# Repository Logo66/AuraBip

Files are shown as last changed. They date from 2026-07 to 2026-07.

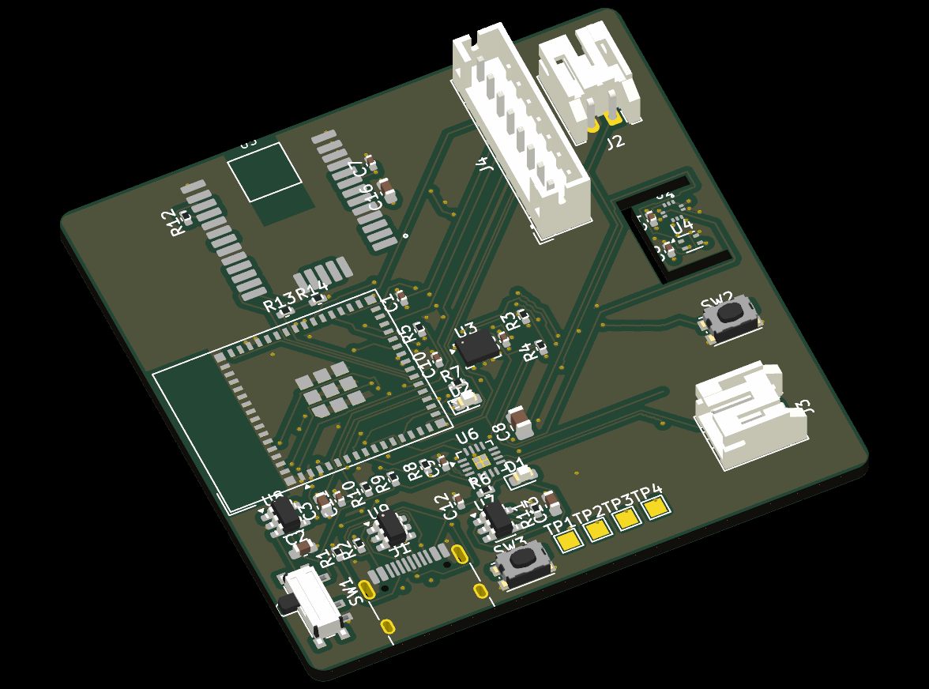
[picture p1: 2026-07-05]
hardware/project/news_persp.jpg

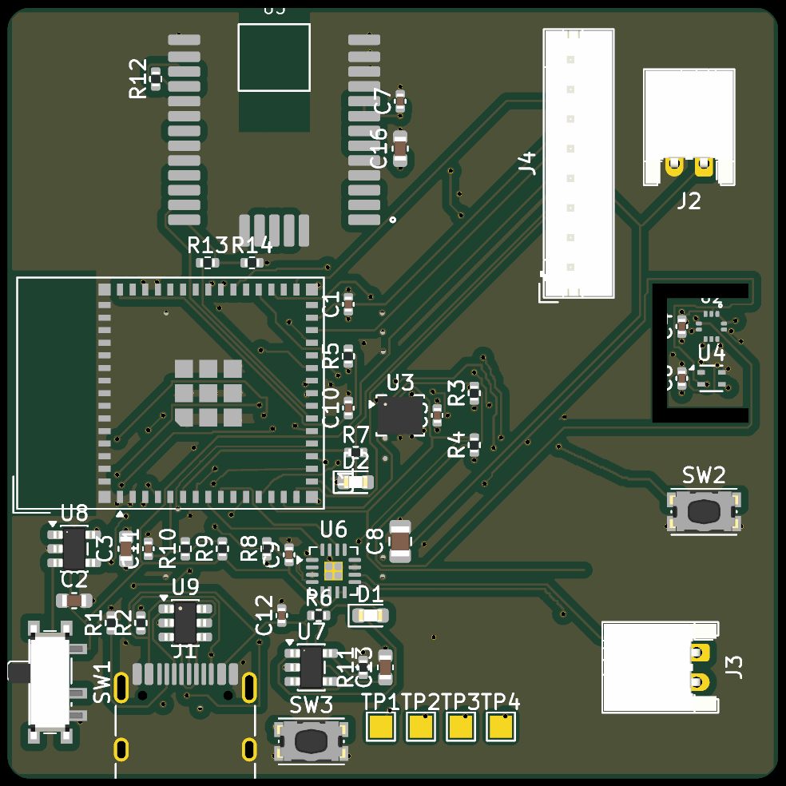
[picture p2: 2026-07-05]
hardware/project/news_top.jpg

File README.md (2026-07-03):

# AuraBip — BLE-Vario auf Heltec V4 (Arbeitstitel)

Minimalistisches BLE-Vario im Stodeus-Stil: Heltec WiFi LoRa 32 V4 + GNSS +
BMP581 + LSM6DSO32 + SHT40. OLED zeigt nur das Nötigste, maximal gross.
Zwei Varianten: **silent** (BLE+Display) und **audio** (I2S-Verstärker,
Vario-Ton + Sprachansagen).

© 2026 KIE Engineering. Proprietär. Clean-Room-Regel wie WindBuddy:
kein Code aus GPL/CC-BY-NC-Projekten (GXAirCom, SoftRF, etc.).
Erlaubt: RadioLib/NimBLE/U8g2 als Bibliotheken (MIT/BSD), öffentliche
Protokoll-Spezifikationen (LK8EX1, NMEA).

## Kernidee "Instant Vario"

Reines Baro-Vario ist träge und böenempfindlich. Die Franzosen (Stodeus)
koppeln deshalb Beschleunigungssensor + Barometer. Wir machen dasselbe:
Kalman-Filter mit BMP581 (Messung, ~50 Hz) + LSM6DSO32 Vertikal-
beschleunigung (Prädiktion, ~200 Hz). Ergebnis: Ansprechzeit <100 ms statt
~1 s, ohne Zappeln.

## BLE-Protokoll (Kompatibilität zu XCTrack / XCSoar / SkyDrop-Apps)

Nordic UART Service (NUS), Notify-Stream mit:
- `$LK8EX1,<press_Pa>,<alt_m>,<vario_cm_s>,<temp_C>,<batt>*CS` — 5 Hz
- NMEA `$GPGGA` / `$GPRMC` Passthrough vom GNSS — 1 Hz
⚠️ VERIFY: LK8EX1-Feldreihenfolge/Checksumme gegen offizielle Doku (T1).

## Display-Philosophie

128×64 OLED, eine einzige Ansicht im Flug:
```
+----------------------+
|  +2.4          ← Vario, riesig (32 px Ziffern)
|  1847 m   34 km/h    ← Alt + GPS-Speed, klein
+----------------------+
```
Kein Menü im Flug. Konfiguration über BLE (BipLink-Prinzip) — Ticket T5.

## Audio-Variante — Realitätscheck

"High Quality Sprach- und Varioton" geht NICHT über den nackten Piezo.
Stodeus-Qualität heisst: richtiger Lautsprecher + Verstärker.
Unser Weg: **MAX98357A I2S-Amp (~3 CHF) + 1 W / 8 Ω Lautsprecher 20–28 mm**.
- Varioton: Synthese direkt auf dem S3 (Sinus/Rechteck, Tonhöhe+Rate aus Vz)
- Sprache: WAV-Samples (16 kHz mono) im 16-MB-Flash — Ansagen Höhe/Speed/
  Steigen auf Doppeltipp (IMU-Tap-Detection des LSM6DSO32, kein Taster nötig!)
Samples: selbst mit TTS generieren (de/en/es — es für Kolumbien 😉).

## Hardware-Verkabelung (v0.1 Prototyp)

| Signal | Heltec V4 Pin | Anmerkung |
|---|---|---|
| I2C SDA/SCL | 17 / 18 (⚠️ VERIFY am V4-Schema) | BMP581 0x47, LSM6DSO32 0x6A, SHT40 0x44 — Ivos Standard-Map |
| GNSS | SH1.25-8P Connector | ⚠️ VERIFY Pinout/UART lt. V4-Doku (T2) |
| OLED | onboard | SSD1306 128×64 |
| I2S (audio) | BCLK/LRCK/DIN frei wählen | in config.h |

## Strategie-Notiz

Hardware-Kosten ~35–45 CHF (Board+Sensoren+GNSS). Als Bausatz das perfekte
Einstiegsprodukt unterhalb der Aura Krücke — und der SX1262 ist ja onboard:
FANET-Upgrade per Firmware-Update ist der eingebaute Upsell (v2).

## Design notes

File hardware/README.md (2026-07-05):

# AuraBip audio — Hardware v0.1 (Serienprodukt)

© 2026 KIE Engineering. Proprietär.

Kompaktes BLE-Vario mit Ton-/Sprachausgabe **und FANET-TX** (FANET→OGN;
ADS-L-ready für den kommenden Conspicuity-Standard): **36×52 mm, 4 Lagen, doppelseitig bestückt**.
Vorderseite: MCU, Sensorik, GNSS, Audio, Power. Rückseite: E22-900M22S
(SX1262) + u.FL-Antennenbuchse. OLED-Modul gesteckt über der Vorderseite,
Akku (LiPo 802030) und Lautsprecher extern per JST-PH.

## Struktur

```
hardware/
  BOM.md          Stückliste + bewusste Design-Entscheide + VERIFY-Tickets
  PINMAP.md       GPIO-Zuordnung, Power-Topologie, komplette Netzliste
  lib/            aurabip.kicad_sym + aurabip.pretty (eigene Symbole/Footprints)
  project/        aurabip.kicad_sch / aurabip.kicad_pcb (generiert!)
  scripts/        generate_schematic.py / generate_pcb.py / symlib.py
  route/          FreeRouting-Pipeline (fanout -> DSN -> route -> import -> DRC)
```

**Alles generiert:** Schema und PCB entstehen aus den Python-Skripten —
Änderungen bitte dort machen und neu generieren, nicht im GUI editieren
(sonst divergiert die Quelle der Wahrheit). Workflow:

```powershell
# 1. Schema (schreibt auch lib/aurabip.kicad_sym + Lib-Tables)
& "C:\Program Files\KiCad\10.0\bin\python.exe" scripts\generate_schematic.py
# 2. ERC
& "C:\Program Files\KiCad\10.0\bin\kicad-cli.exe" sch erc project\aurabip.kicad_sch
# 3. PCB (Platzierung + Zonen, ohne Tracks; zieht Netzliste aus dem Schema)
& "C:\Program Files\KiCad\10.0\bin\python.exe" scripts\generate_pcb.py
# 4. Routing + DRC
powershell -File route\run_autoroute.ps1   # -> project\aurabip_routed.kicad_pcb
```

## Floorplan (Blick von oben)

```
+--------------------------------+
|      L96 GNSS (Patch oben)     |  <- Antenne Richtung Himmel
|                        [AKKU]  |
| ESP32-S3    BMP581  SHT40      |
| (Antenne    LSM6DSO32   [OLED- |
|  -> links)  Pullups      Hdr]  |
| LDO  Teiler  MAX98357A         |
| SW1  USBLC6  Lader  [SPEAKER]  |
| [RST] USB-C [BOOT]  Testpads   |
+--------------------------------+
```

- **ESP32-Antenne**: linke Kante, Kupfer-Keepout auf allen Lagen (x 0–6.0, y 17.7–34.3)
- **L96-Patch**: obere Kante, GND-Lage bleibt darunter (Quectel-Empfehlung, VERIFY T-H5)
- **BMP581/SHT40**: nahe Boardkante; fürs Gehäuse Druckausgleichs-/Lüftungsöffnung vorsehen
- **Rückseite**: E22-900M22S mittig (Handbestückung), u.FL darunter — 868-Flexantenne
  im Gehäuse verlegen, weg von GNSS-Patch und BLE-Antenne (T-H8)
- Lagen: F=Signal+GND-Pour, In1=GND, In2=+3V3, B=Signal+GND-Pour

## Fertigung

- JLCPCB 4-Lagen, 1.6 mm, min. Track/Clearance 0.10 mm (Via 0.5/0.3),
  Bohrloch→Kupfer 0.2 mm — Standardprozess (T-H1 verifizieren)
- SMT-Bestückung (Vorderseite): alle Passiven 0402/0603 aus JLC-Basic-Sortiment
- Handbestückung: L96, JST-Stecker, OLED-Header, Rückseite (E22, u.FL, C14/C15)

## Firmware-Anpassung

Serien-Board ≠ Heltec-Prototyp — `src/config.h` braucht die Pin-Werte aus
[PINMAP.md](PINMAP.md) (I2C 8/9, GNSS 17/18, I2S 4/5/6, neu: AMP_SD 7,
VBAT_ADC 1, LED 2, BTN 0, LoRa-SPI 21/12/11/13 + BUSY 14/DIO1 3/RST 15/
TXEN 16/RXEN 37; OLED auf dem Sensorbus, kein Vext).

**FANET-TX**: Encoder aus WindBuddy `lib/fanet` übernehmen (eigener
Clean-Room-Code, Tracking Typ 1 statt Wetter Typ 4). RadioLib mit
`setRfSwitchPins(RXEN, TXEN)`. TX-Leistung hart ≤ 14 dBm ERP (T-H8),
nur im Flug senden, Adresse/Manufacturer wie WindBuddy-Konvention.

## Offene VERIFY-Tickets (vor Bestellung!)

| Ticket | Was |
|---|---|
| T-H1 | LCSC-Nummern + Lagerbestand aller Positionen |
| T-H2 | **L96-Padout** gegen Quectel Hardware Design Guide (Footprint ist Annahme!) |
| T-H3 | MAX98357A: TQFN-Pinnummern + Exposed-Pad-Maß gegen Maxim-Datenblatt |
| T-H4 | LSM6DSO32-Pinout (INT1=Pin 4?) gegen ST-Datenblatt |
| T-H5 | Antennen-Regeln: ESP32-Keepout-Maße + GND unter L96-Patch |
| T-H6 | USB-C-Footprint-Orientierung: Stecker muss über die Boardkante ragen |

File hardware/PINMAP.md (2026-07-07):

# AuraBip audio — Pin-Map & Netzliste v0.1

© 2026 KIE Engineering. Proprietär.

## ESP32-S3-MINI-1 GPIO-Zuordnung

| GPIO | Netz | Funktion | Anmerkung |
|---|---|---|---|
| 0 | BTN_BOOT | Taster BOOT/USER | Strapping; im Betrieb Nutzertaste |
| 1 | VBAT_SENSE | ADC1_CH0, Teiler 1M/1M + 100n | VBAT/2, max 2.15 V ✓ |
| 2 | LED_STATUS | Status-LED (blau) | aktiv high |
| 4 | I2S_BCLK | MAX98357A BCLK | |
| 5 | I2S_LRCK | MAX98357A LRC | |
| 47 | I2S_DOUT | MAX98357A DIN | Routing-Umzug 2026-07-06: von IO6 auf IO47 verlegt |
| 7 | AMP_SD | MAX98357A SD_MODE | high = an (mono L+R/2); 100k-Pullup an 3V3 |
| 8 | I2C_SDA | Sensorbus + OLED | 4.7k-Pullup |
| 9 | I2C_SCL | Sensorbus + OLED | 4.7k-Pullup |
| 10 | IMU_INT1 | LSM6DSO32 INT1 | Tap-Detection / Data-Ready |
| 17 | GNSS_RX | ← L96 TXD | UART1 RX |
| 18 | GNSS_TX | → L96 RXD | UART1 TX |
| 19 | USB_DN | USB D− | über USBLC6 |
| 20 | USB_DP | USB D+ | über USBLC6 |
| 3 | LORA_DIO1 | E22 DIO1 (IRQ) | |
| 11 | SPI2_MOSI | E22 MOSI + OLED DIN | geteilter SPI2-Bus |
| 12 | SPI2_SCK | E22 SCK + OLED CLK | geteilter SPI2-Bus |
| 13 | SPI2_MISO | E22 MISO | OLED hat kein MISO |
| 14 | LORA_BUSY | E22 BUSY | |
| 15 | LORA_RST | E22 NRST | |
| 16 | LORA_TXEN | E22 TXEN | RadioLib setRfSwitchPins |
| 21 | LORA_NSS | E22 NSS | SPI CS LoRa |
| 33 | OLED_CS | Display Chip-Select | |
| 34 | OLED_DC | Display Data/Command | |
| 35 | OLED_RST | Display Reset | |
| 37 | LORA_RXEN | E22 RXEN | RadioLib setRfSwitchPins (IO26 ist Flash-reserviert) |
| EN | ESP_EN | RESET-Taster + 10k-Pullup + 1µF | |

Display: 1.5" 128×128 SSD1327 über SPI (U8g2: `U8G2_SSD1327_WS_128X128` o. ä.,
Controller nach Lieferung verifizieren, T-H9). I2C-Bus bleibt nur für Sensorik.

Frei/Reserve: 6, 38–46, 48 → 4 Testpads (TP1–TP4: 38, 40, 41, 42).
(IO6 seit Routing-Umzug 2026-07-06 frei, I2S_DOUT liegt auf IO47.)

**config.h-Änderungen für Serien-Board** (gegenüber Heltec-Prototyp):
`PIN_I2C_SDA 8, PIN_I2C_SCL 9, PIN_GNSS_RX 17, PIN_GNSS_TX 18,
PIN_I2S_BCLK 4, PIN_I2S_LRCK 5, PIN_I2S_DOUT 47` + neu `PIN_AMP_SD 7,
PIN_VBAT_ADC 1, PIN_LED 2, PIN_BTN 0`. OLED auf demselben Bus (0x3C),
kein Vext, kein separater OLED-Bus.

## Stromversorgung

```
USB-C 5V ──┬── MCP73831 ──── VBAT ──┬── JST-PH Akku (802030, 500 mAh)
           │   (500 mA, STAT→LED)   ├── MAX98357A VDD (22µF Puffer)
           └── USBLC6 ── D+/D−      └── SW1 ─→ AP2112K EN
                                            AP2112K: VBAT → 3V3
3V3 ── ESP32-S3, L96 (VCC+V_BCKP), BMP581, LSM6DSO32, SHT40, OLED,
       Pullups (I2C, AMP_SD, EN)
```

- SW1 schaltet nur das LDO-EN gegen VBAT/GND → Laden funktioniert im Aus-Zustand, kein Laststrom über den Schalter.
- Amp ist bei 3V3=aus über SD_MODE (Pullup an 3V3 → low) im Shutdown (<1 µA).
- L96 V_BCKP an 3V3: kein Warmstart nach „Aus" (bewusst — Backup-Zelle gespart; Kaltstart ~35 s).

## I2C-Bus (400 kHz, ein Bus)

| Gerät | Adresse |
|---|---|
| BMP581 | 0x47 (SDO→3V3) |
| LSM6DSO32 | 0x6A (SA0→GND) |
| SHT40 | 0x44 |
| OLED SSD1306 | 0x3C |

## Vollständige Netzliste (Referenz für Generatoren)

| Netz | Pins |
|---|---|
| GND | alle GND-Pads, USB-Shield, EP U6, CC-Rs low-side n/a |
| VBUS | J1.VBUS, U9.VBUS, U7.IN(4), 100n |
| VBAT | U7.OUT(3), J2.1, U6.VDD, SW1-Mitte n/a → U8.IN(1)+EN-Kette, R-Teiler oben |
| +3V3 | U8.OUT(5), U1.3V3, U2, U3, U4, U5.VCC+V_BCKP, J4.VCC, Pullups |
| USB_DP/USB_DN | J1.D±(A6/B6, A7/B7) ↔ U9 ↔ U1.IO20/IO19 |
| CC1/CC2 | J1.CC1/CC2 → je 5.1k → GND |
| CHG_STAT | U7.STAT(1) → LED grün → 3V3 (aktiv low) |
| PROG | U7.PROG(5) → 2k → GND |
| LDO_EN | U8.EN(3) ← SW1 (VBAT / GND) |
| ESP_EN | U1.EN ← 10k→3V3, 1µF→GND, SW2→GND |
| BTN_BOOT | U1.IO0 ← SW3→GND (interner Pullup) |
| I2C_SDA/SCL | s. oben, 4.7k→3V3 |
| I2S_BCLK/LRCK/DOUT | U1.IO4/5/47 → U6.BCLK/LRC/DIN (DOUT: Routing-Umzug 2026-07-06, IO6→IO47) |
| AMP_SD | U1.IO7 → U6.SD_MODE, 100k→3V3 |
| AMP_OUTP/OUTN | U6.OUT+/OUT− → J3 (Lautsprecher) |
| IMU_INT1 | U3.INT1 → U1.IO10 |
| GNSS_TX_NET | U5.TXD → U1.IO17 |
| GNSS_RX_NET | U5.RXD ← U1.IO18 |
| VBAT_SENSE | Teiler-Mitte → U1.IO1 |
| LED_STATUS | U1.IO2 → 1k → LED blau → GND |
| LORA_NSS/SCK/MOSI/MISO | U1.IO21/12/11/13 → U10 (E22-900M22S) |
| LORA_BUSY/DIO1/RST | U10 → U1.IO14/IO3/IO15 |
| LORA_TXEN/RXEN | U1.IO16/IO37 → U10 |
| LORA_ANT | U10.ANT → J5 (u.FL); E22 an +3V3 (TX 14 dBm ≈ 120 mA ok) |

⚠️ VERIFY: MAX98357A-GAIN-Pin offen lassen = 9 dB (Default). Bei Bedarf
GAIN-Netz auf Lötjumper führen — v0.1: offen.

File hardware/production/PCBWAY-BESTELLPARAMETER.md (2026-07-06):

# PCBWay-Bestellparameter AuraBip v0.1 (für die Offerte)

## PCB (Instant Quote → Standard PCB)
| Parameter | Wert |
|---|---|
| Board size | 52 × 52 mm |
| Quantity | **10** (Prototypen-Charge) |
| Layers | **4** |
| Material | FR-4, TG150 |
| Thickness | 1.6 mm |
| Min track/spacing | **5/5 mil** (0.127 mm Schmalspur-Züge!) |
| Min hole size | 0.3 mm |
| Solder mask | Grün (oder nach Geschmack) |
| Silkscreen | Weiß |
| Surface finish | **ENIG** (0.4-mm-Pitch BMP581 + Stamp-Holes — kein HASL!) |
| Via process | Tenting vias |
| Kupfer | 1 oz außen / 0.5 oz innen (Standard) |
| Besonderheit | **Interne Fräskontur** (Sensor-Insel, C-Schlitz 1 mm) — ist in Edge.Cuts enthalten |

## Assembly (Turnkey, nur Vorderseite)
| Parameter | Wert |
|---|---|
| Seiten | **Nur Top** (Bottom = 4 Teile Handbestückung durch uns: E22, C14, C15) |
| Anzahl | 10 Boards bestücken |
| Teile-Beschaffung | Turnkey (PCBWay beschafft); **U5 (Quectel L96) + U10 (E22) ggf. als Consigned/selbst liefern**, falls Beschaffung teuer |
| Stencil | Ja (framework-los reicht) |
| Dateien | aurabip_gerber.zip · aurabip-bom.csv · aurabip-top-pos.csv (+ bottom-pos nur zur Referenz) |

## Hinweise für die Review durch PCBWay
- 0402-Passive, TQFN-16 (0.5 P), LGA-10 (0.4 P!), LGA-14 (0.5 P), DFN-4
- USB-C-Buchse ragt 1.2 mm über die Kante (Absicht)
- NPTH: Schalter-Justierstifte + USB-Schild
- Bottom-Bauteile im Pick&Place enthalten, aber NICHT bestücken

## Nach Offerten-Eingang prüfen (T-H1)
- [ ] Alle BOM-Zeilen gematcht? (Passive ohne MPN → PCBWay-Vorschlag akzeptieren, X7R/1% reicht)
- [ ] L96 + E22 lieferbar/Preis ok? Sonst consigned liefern
- [ ] ME6217C33M5G verfügbar? (Fallback: AP2112K-3.3, pinkompatibel, dann aber LoRa-TX + BLE-Peak nicht gleichzeitig — FW drosseln)
- [ ] Keine Design-Rückfragen zu Schmalspur/Fräsung offen

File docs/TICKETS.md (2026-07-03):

# AuraBip — Tickets (Claude Code)

Clean-Room-Regel wie WindBuddy gilt. Kein GXAirCom/SoftRF-Code anschauen.

## T1 — LK8EX1 & BLE-Kompatibilität (BLOCKER)
- LK8EX1-Spez beschaffen, Feldkonventionen verifizieren (Batteriefeld!)
- Test gegen XCTrack auf Ivos Handy: verbindet, zeigt Baro-Alt + Vario + GPS?
- BLE-Name/Advertising so, dass XCTrack das Gerät als "BLE Sensor" findet
- DoD: XCTrack fliegt komplett mit AuraBip-Daten (interner Sensor aus)

## T2 — Sensortreiber & GNSS
- BMP581/LSM6DSO32/SHT40-Treiber aus Aura-Monorepo portieren (eigener Code)
- BMP581: OSR/ODR für 50 Hz rauscharm konfigurieren
- V4 GNSS-Connector-Pinout aus Heltec-Doku verifizieren, MAX-M10S anbinden
- RMC-Parser härten (kein strstr-Gefrickel)
- DoD: sensors::init() erkennt alle drei, Live-Werte plausibel

## T3 — Orientierungsschätzung
- verticalAccelApprox() durch Mahony-Filter (Gyro+Accel) ersetzen,
  echte Erd-Frame-Vertikalbeschleunigung
- Kalman-Tuning im Auto-/Treppenhaus-Test, dann Flug
- DoD: Ansprechzeit < 150 ms, kein Zappeln im Geradeausflug

## T4 — Audio-Ausbau (Variante audio)
- WAV-Player aus LittleFS, Mixer (Ansage über gedämpftem Varioton)
- Tap-Detection LSM6DSO32 (Doppeltipp = Ansage Höhe/Speed)
- Sprachsamples de/en/es generieren (TTS), 16 kHz mono
- Lautstärke-Profil: Start laut, konfigurierbar via BLE
- DoD: Doppeltipp -> saubere Sprachansage ohne Knacken, Ton läuft weiter

## T5 — BLE-Konfigurationskanal
- Zweite NUS-Charakteristik (RX): einfache Key=Value-Kommandos
  (QNH, Lautstärke, Klimm-/Sinkschwellen, Sprachwahl)
- Persistenz in NVS
- DoD: Einstellung überlebt Reboot

## T6 — Strom & Gehäuse
- Light-Sleep-Strategie am Boden (kein Steigen 10 min -> Display dim, IMU-Wakeup)
- Verbrauchsmessung beide Varianten; Ziel: >20 h mit 3000er Zelle
- Ivo: Gehäuse-Design (Druck), Lautsprecheröffnung akustisch (Bassreflex-Schlitz)

## Später / v2
- FANET über den onboard SX1262 (lib/fanet aus WindBuddy wiederverwenden!)
- IGC-Logging in Flash

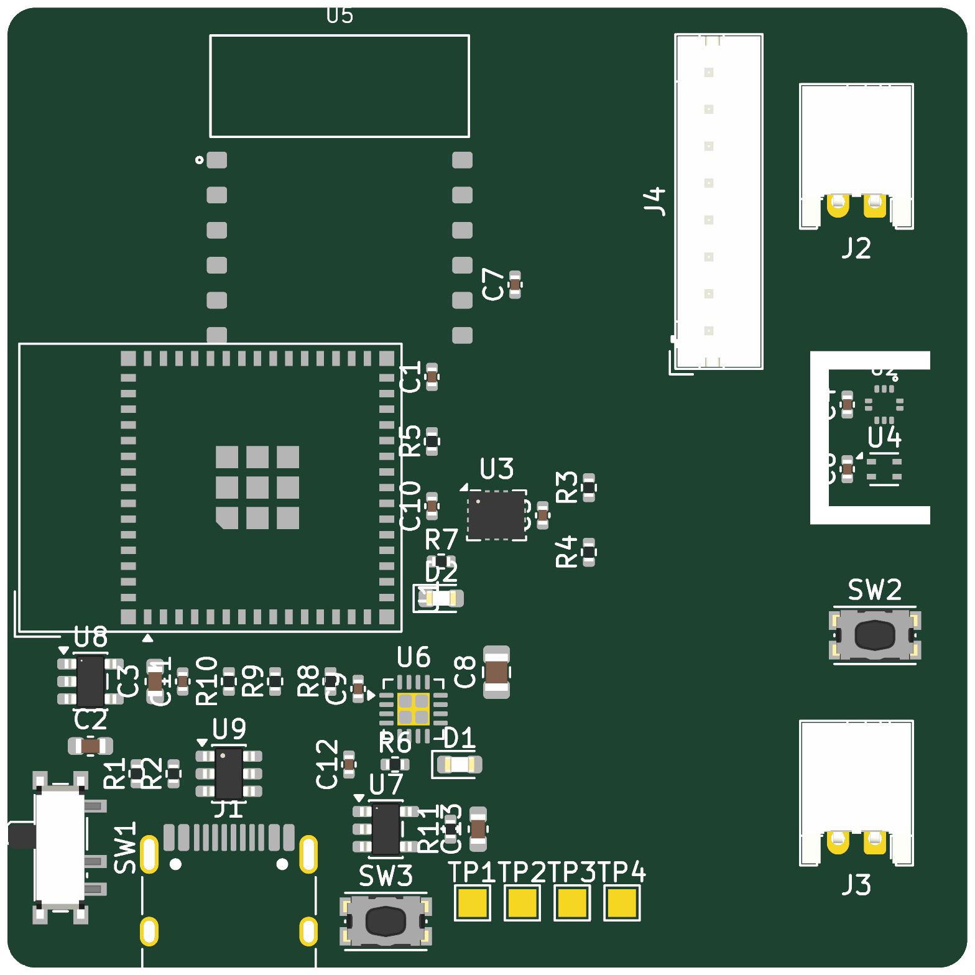
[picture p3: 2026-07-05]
hardware/project/render_52_top.png

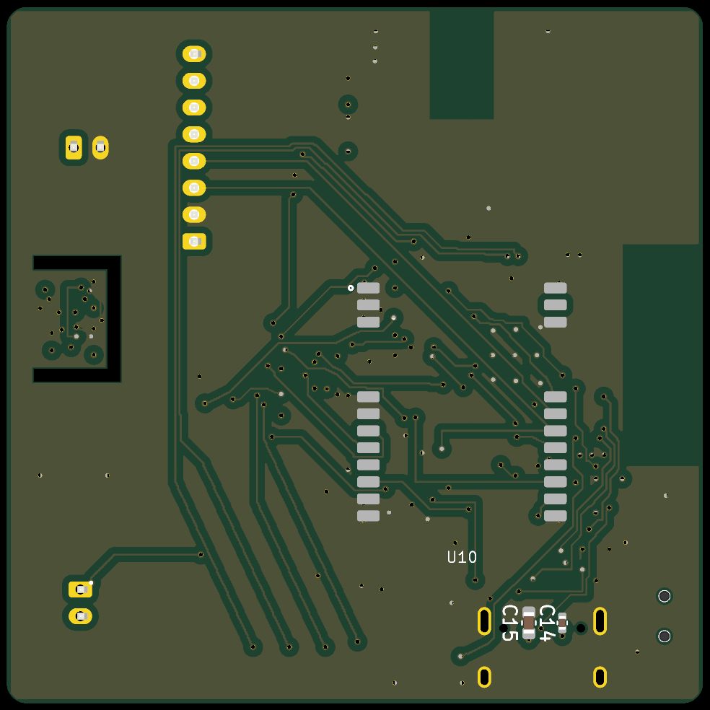
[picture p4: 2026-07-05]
hardware/project/news_bottom.jpg

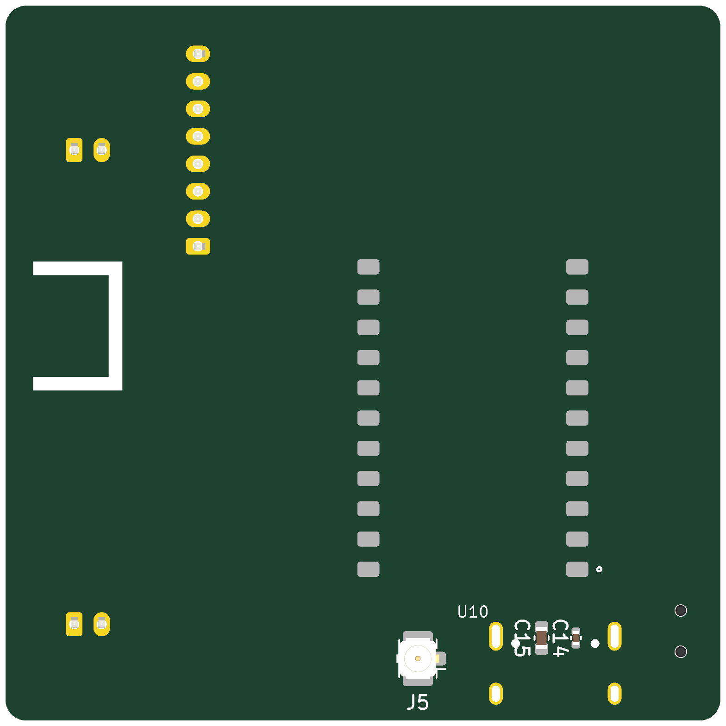
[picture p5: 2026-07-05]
hardware/project/render_52_bottom.png

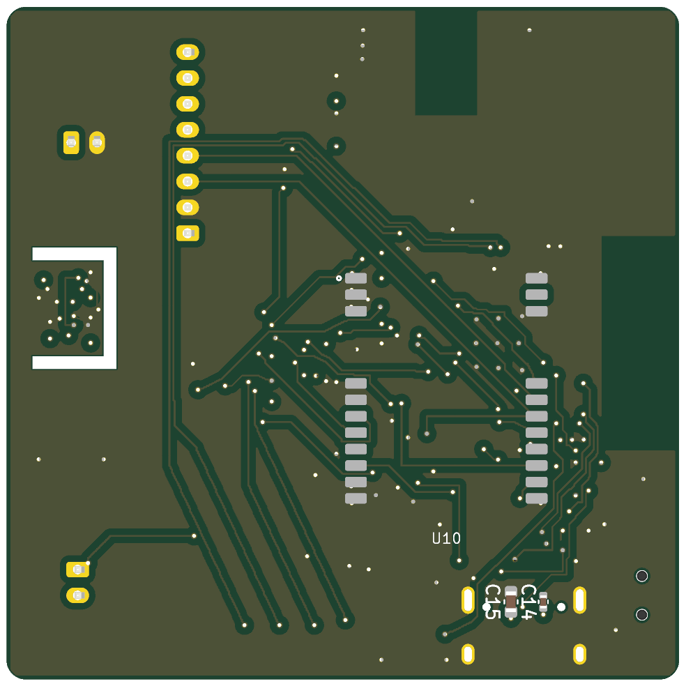
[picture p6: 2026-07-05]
hardware/project/news_bottom.png

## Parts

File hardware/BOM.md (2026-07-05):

# AuraBip audio — BOM v0.1 (Serienprodukt)

© 2026 KIE Engineering. Proprietär.

Ziel: kompaktes BLE-Vario mit Sprach-/Tonausgabe, ~35×48 mm, 4-Lagen-PCB,
JLCPCB-Fertigung (SMT-Bestückung ab Rolle wo möglich).
Alle LCSC-Nummern sind ⚠️ **vor Bestellung zu verifizieren** (Verfügbarkeit dreht schnell).

## Kern

| Ref | Bauteil | Package | Funktion | LCSC (⚠️ prüfen) | ~Preis (1 Stk) |
|---|---|---|---|---|---|
| U1 | **ESP32-S3-MINI-1-N8** | Modul 15.4×15.4 | MCU, BLE 5, natives USB (kein UART-Bridge-Chip nötig), FCC/CE-zertifiziert | C2913204 | 3.20 CHF |
| U2 | **BMP581** | LGA-10 2×2 | Barometer 50 Hz (Kalman-Update), Adr 0x47 | TBD | 2.50 CHF |
| U3 | **LSM6DSO32XTR** | LGA-14 2.5×3 | IMU ±32 g, 200 Hz Prädiktion + Tap-Detection, Adr 0x6A | TBD | 2.80 CHF |
| U4 | **SHT40-AD1B** | DFN-4 1.5×1.5 | Temp/Feuchte, Adr 0x44 | TBD | 1.80 CHF |
| U5 | **Quectel L96-M33** | LCC 14×15 | GNSS MT3333, **integrierte Patch-Antenne** (kein RF-Design-Risiko), 1 Hz NMEA | TBD | 6.50 CHF |
| U6 | **MAX98357AETE+T** | TQFN-16-EP 3×3 | I2S-DAC+3.2W-Class-D-Amp, läuft direkt an VBAT | TBD | 2.20 CHF |

## Power

| Ref | Bauteil | Package | Funktion | LCSC (⚠️ prüfen) | ~Preis |
|---|---|---|---|---|---|
| U10 | **Ebyte E22-900M22S** | Modul 16×26 | SX1262 + TCXO + PA, FANET-TX (Typ 1) → OGN-Sichtbarkeit; GFSK-fähig = **ADS-L-ready** für den kommenden Conspicuity-Standard. TX-Leistung in FW hart auf 14 dBm ERP begrenzt | TBD | 5.50 CHF |
| ANT | **Molex 105262-0001** Flex-Klebeantenne 868/915, u.FL, 100 mm Kabel (Alt.: Taoglas FXP14; -0002 = 150 mm) | im Gehäuse (Wandnische, vertikal) | steckt **direkt auf die IPX-Buchse des E22-Moduls** — null Board-RF, kein eigener Antennenanschluss (J5 entfallen). Nischenmaß im Fusion-Skript anpassen (ant_l/ant_h) | Beta LAYOUT ~8 € | 8.00 CHF |
| U7 | **MCP73831T-2ACI/OT** | SOT-23-5 | LiPo-Lader 1 Zelle, 500 mA (R_PROG 2 kΩ) | C424093 | 0.60 CHF |
| U8 | **ME6217C33M5G** | SOT-23-5 | LDO 3.3 V / **800 mA** (ESP32-BLE-Peak + LoRa-TX + GNSS gleichzeitig; Amp hängt an VBAT). Pinkompatibel zu AP2112K | C82942 (⚠️) | 0.20 CHF |
| U9 | **USBLC6-2SC6** | SOT-23-6 | USB-ESD-Schutz | C7519 | 0.20 CHF |
| J1 | **TYPE-C-31-M-12** (HRO) | USB-C 16P | Laden + Flashen (USB-CDC/DFU) | C165948 | 0.25 CHF |
| J2 | **JST PH 2P** (S2B-PH-K-S) | THT gewinkelt | Akku-Anschluss | TBD | 0.10 CHF |
| BAT | **LiPo 504050**, 3.7 V, **1500 mAh**, 52×42×5 mm, 25 g, −25…+60 °C, Kabel 45 mm, JST-PH 2.0 | extern, unter dem 52×52-Board (Gehäuse-Schacht) | ~10 h Laufzeit bei ~140 mA Mix; Betriebstemp. bis −25 °C ist flugtauglich. ⚠️ **POLARITÄT am Stecker prüfen** — bei LiPo-Herstellern nicht genormt! | ~9 CHF | 9.00 CHF |
| SW1 | **MSK-12C02** | Schiebeschalter | Ein/Aus (schaltet nur LDO-EN, nicht VBAT — Laden geht auch „aus") | TBD | 0.15 CHF |

## Audio & UI

| Ref | Bauteil | Package | Funktion | LCSC (⚠️ prüfen) | ~Preis |
|---|---|---|---|---|---|
| LS1/J3 | **Visaton K 28 WP** (28 mm, 8 Ω, 1 W, spritzwassergeschützte Kunststoffmembran) an JST-PH-Pigtail | — | Varioton + Sprache; WP-Variante wegen Outdoor-Einsatz | Voelkner/RS/Reichelt ~4 CHF | 4.00 CHF |
| J4 | **JST-PH 8-Pin vertikal** (B8B-PH-K-S) + **Waveshare 1.32" OLED** 128×96, 16 Graustufen, SSD1327, SPI | Kabel (liegt Modul bei) | Kein Header — Modul hat **PH2.0-Buchse**, Kabel im Lieferumfang → Display frei im Gehäusedeckel platzierbar. Teilt SPI2 mit E22 (eigener CS); −20…70 °C. T-H9: Kabel-Pinreihenfolge bei Lieferung prüfen | Waveshare/Amazon ~12 CHF | 12.00 CHF |
| SW2 | Taster **RESET** (EN) | SMD 3.9×2.9 | Neustart | TBD | 0.05 CHF |
| SW3 | Taster **BOOT/USER** (GPIO0) | SMD 3.9×2.9 | Strapping + Nutzertaste im Betrieb (Doppeltipp macht die IMU) | TBD | 0.05 CHF |
| D1 | LED grün + R 1 kΩ | 0603 | Lade-Status (MCP73831 STAT) | — | 0.03 CHF |
| D2 | LED blau + R 1 kΩ | 0603 | Status (GPIO2) | — | 0.03 CHF |

## Passiv (0402, JLC Basic Parts)

| Menge | Wert | Funktion |
|---|---|---|
| 2× | 5.1 kΩ | USB-C CC1/CC2 |
| 2× | 4.7 kΩ | I2C-Pullups SDA/SCL |
| 1× | 2 kΩ | MCP73831 PROG (500 mA) |
| 2× | 1 MΩ | VBAT-ADC-Teiler (GPIO1) |
| 1× | 100 kΩ | Amp SD_MODE-Pullup auf 3V3 (aus, wenn 3V3 aus) |
| 1× | 10 kΩ | EN-Pullup (RESET) |
| 8× | 100 nF | Abblock je IC |
| 2× | 10 µF | LDO in/out |
| 1× | 22 µF (0805) | Amp-VBAT-Puffer |
| 1× | 100 nF | ADC-Teiler-Filter |

**Summe Elektronik: ~31 CHF/Stk** (Kleinserie 50 Stk, ohne PCB/Bestückung/Akku/Gehäuse).
PCB+SMT bei JLC (50 Stk, 4-Lagen): ~9 CHF/Board. Akku 802030: ~3 CHF. Antenne 868: ~1 CHF. → **~44 CHF Material.**

## Bewusste Entscheidungen

- **FANET-TX drin** (Änderung 2026-07-03): Elektronische Sichtbarkeit (Conspicuity) ist absehbar — Standard-Kandidat ist **ADS-L**, ein festes Pflichtdatum gibt es noch nicht. SX1262-Modul E22-900M22S: sendet heute FANET→OGN, GFSK-fähig für späteres ADS-L-out per Firmware. **Nur TX** (Tracking Typ 1, FANET→OGN), keine Warnlogik — Warnquellen-Philosophie bleibt. FANET-Encoder aus WindBuddy `lib/fanet` (eigener Clean-Room-Code) wiederverwenden. Modul statt nacktem SX1262: TCXO (Frequenzstabilität bei Kälte!) + fertiges RF-Frontend.
- **Kein USB-UART-Chip**: ESP32-S3 natives USB (GPIO19/20) für Flashen + CDC-Logs.
- **Kein Fuel-Gauge** (v1): VBAT-Teiler an ADC reicht für %-Anzeige. v2-Option: MAX17048.
- **Kein Power-Path** (v1): MCP73831 lädt, System zieht parallel an VBAT. Bekannte Schwäche: Terminierung bei Last ungenau. v2-Option: BQ24074.
- **L96 mit integrierter Antenne** statt ATGM336H+Antenne: teurer, aber null RF-Layout-Risiko und kleiner als Patch+Pigtail.
- **Amp an VBAT**: Audio-Peaks (~1 A kurz) gehen nicht durch den 600-mA-LDO. SD_MODE-Pullup an 3V3 schaltet den Amp mit aus.

## VERIFY-Status (Stand 2026-07-05)

| Ticket | Status |
|---|---|
| T-H2 L96-Padout | ✅ **verifiziert** gegen Quectel HW Design V1.4 (LCC-31, 14×9.6! RF-Brücke R12 + RXD-Teiler R13/R14 ergänzt, Antennen-Keepout 4.8×7.3) |
| T-H3 MAX98357A | ✅ **verifiziert** gegen ADI-Datenblatt Rev 7 (TQFN-Pinout war falsch → korrigiert; Footprint auf EP1.23 gewechselt; GAIN offen = 9 dB bestätigt) |
| T-H4 LSM6DSO32 | ✅ **verifiziert** gegen ST-Datenblatt Rev 1 (Pinout korrekt; Footprint auf ST-LayoutBorder3x4y gewechselt) |
| T-H7 E22-900M22S | ✅ **verifiziert** gegen Ebyte Manual v1.3 (war 14×20/1.27er-Pitch statt 16×26/2.2 — komplett neu; JLC C411293) |
| T-H1 LCSC/PCBWay-Nummern + Lager | ⏳ offen — bei Bestellung gegen PCBWay-Sortiment prüfen |
| T-H5 ESP32-Antennen-Keepout-Maße | ⏳ offen (konservativ ausgelegt) |
| T-H6 USB-C-Überstand | ⏳ offen — 1.2 mm Nase, am ersten Board messen |
| T-H8 Regulatorik 14 dBm ERP + Duty Cycle | ⏳ offen (vor Verkauf, mit Antennengewinn rechnen) |
| T-H9 OLED-Kabel-Aderreihenfolge | ⏳ offen — bei Lieferung Sichtprüfung |

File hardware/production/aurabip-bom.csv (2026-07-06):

Designator | Qty | MPN | Manufacturer | Description | Footprint | Side
C1,C11,C12,C4,C5,C6,C7,C9 | 8 |  |  | MLCC Capacitor X7R 16V 100n C_0402_1005Metric | C_0402_1005Metric | Top
C10 | 1 |  |  | MLCC Capacitor X7R 16V 1u C_0402_1005Metric | C_0402_1005Metric | Top
C13 | 1 |  |  | MLCC Capacitor X7R 16V 4.7u C_0603_1608Metric | C_0603_1608Metric | Top
C14 | 1 |  |  | MLCC Capacitor X7R 16V 100n C_0402_1005Metric | C_0402_1005Metric | Bottom
C15 | 1 |  |  | MLCC Capacitor X7R 16V 10u C_0603_1608Metric | C_0603_1608Metric | Bottom
C16,C2,C3 | 3 |  |  | MLCC Capacitor X7R 16V 10u C_0603_1608Metric | C_0603_1608Metric | Top
C8 | 1 |  |  | MLCC Capacitor X7R 16V 22u C_0805_2012Metric | C_0805_2012Metric | Top
D1 | 1 | 19-217/GHC-YR1S2/3T | Everlight | LED green 0603 | LED_0603_1608Metric | Top
D2 | 1 | 19-217/BHC-ZL1M2RY/3T | Everlight | LED blue 0603 | LED_0603_1608Metric | Top
J1 | 1 | TYPE-C-31-M-12 | HRO | USB-C receptacle 16P | USB_C_Receptacle_HRO_TYPE-C-31-M-12 | Top
J2 | 1 | S2B-PH-K-S | JST | Battery connector PH 2.0 2P, THT | JST_PH_S2B-PH-K_1x02_P2.00mm_Horizontal | Top
J3 | 1 | S2B-PH-K-S | JST | Speaker connector PH 2.0 2P, THT | JST_PH_S2B-PH-K_1x02_P2.00mm_Horizontal | Top
J4 | 1 | B8B-PH-K-S | JST | OLED connector PH 2.0 8P vertical, THT | JST_PH_B8B-PH-K_1x08_P2.00mm_Vertical | Top
R1,R2 | 2 |  |  | Chip Resistor 1% 5.1k R_0402_1005Metric | R_0402_1005Metric | Top
R11,R14 | 2 |  |  | Chip Resistor 1% 2k R_0402_1005Metric | R_0402_1005Metric | Top
R12 | 1 |  |  | Chip Resistor 1% 0R R_0402_1005Metric | R_0402_1005Metric | Top
R3,R4 | 2 |  |  | Chip Resistor 1% 4.7k R_0402_1005Metric | R_0402_1005Metric | Top
R5 | 1 |  |  | Chip Resistor 1% 10k R_0402_1005Metric | R_0402_1005Metric | Top
R13,R6,R7 | 3 |  |  | Chip Resistor 1% 1k R_0402_1005Metric | R_0402_1005Metric | Top
R8 | 1 |  |  | Chip Resistor 1% 100k R_0402_1005Metric | R_0402_1005Metric | Top
R10,R9 | 2 |  |  | Chip Resistor 1% 1M R_0402_1005Metric | R_0402_1005Metric | Top
SW1 | 1 | MSK-12C02 | Shouhan | Slide switch | SW_SPDT_PCM12 | Top
SW2 | 1 | KMR221GLFS | C&K | Tactile switch RESET | SW_Push_1P1T_NO_CK_KMR2 | Top
SW3 | 1 | KMR221GLFS | C&K | Tactile switch BOOT | SW_Push_1P1T_NO_CK_KMR2 | Top
TP1,TP2,TP3,TP4 | 4 |  |  | TP TP TestPoint_Pad_1.5x1.5mm | TestPoint_Pad_1.5x1.5mm | Top
U1 | 1 | ESP32-S3-MINI-1-N8 | Espressif | WiFi/BLE module, 8MB flash | ESP32-S2-MINI-1 | Top
U10 | 1 | E22-900M22S | Ebyte | SX1262 LoRa module, stamp holes, bottom side | E22_900M22S | Bottom
U2 | 1 | BMP581 | Bosch | Barometric pressure sensor LGA-10 - open port, do NOT wash | BMP581_LGA-10_2x2mm | Top
U3 | 1 | LSM6DSO32XTR | ST | IMU +/-32g LGA-14 | LGA-14_3x2.5mm_P0.5mm_LayoutBorder3x4y | Top
U4 | 1 | SHT40-AD1B-R2 | Sensirion | Temp/humidity sensor DFN-4 | Sensirion_DFN-4_1.5x1.5mm_P0.8mm_SHT4x_NoCentralPad | Top
U5 | 1 | L96-M33 | Quectel | GNSS module with integrated antenna | Quectel_L96 | Top
U6 | 1 | MAX98357AETE+T | Analog Devices | I2S Class-D amplifier TQFN-16 | TQFN-16-1EP_3x3mm_P0.5mm_EP1.23x1.23mm | Top
U7 | 1 | MCP73831T-2ACI/OT | Microchip | LiPo charger SOT-23-5 | SOT-23-5 | Top
U8 | 1 | ME6217C33M5G | MicrOne | LDO 3.3V 800mA SOT-23-5 | SOT-23-5 | Top
U9 | 1 | USBLC6-2SC6 | ST | USB ESD protection SOT-23-6 | SOT-23-6 | Top

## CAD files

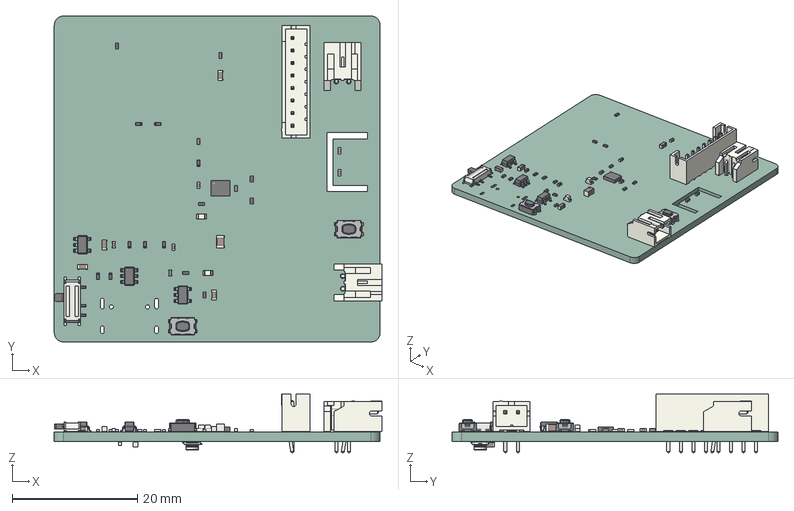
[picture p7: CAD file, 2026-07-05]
hardware/production/aurabip.step
52.2 x 52.0 x 9.40 mm
R_0402_1005Metric x 14
C_0402_1005Metric x 10
SOT-23-5 x 2
C_0603_1608Metric x 5
JST_PH_S2B-PH-K_1x02_P2.00mm_Horizontal x 2
LED_0603_1608Metric x 2
LGA-14_3x2.5mm_P0.5mm_LayoutBorder3x4y
SW_SPDT_PCM12
C_0805_2012Metric
JST_PH_B8B-PH-K_1x08_P2.00mm_Vertical
SW_Push_1P1T_NO_CK_KMR2 x 2
SOT-23-6
U.FL_Hirose_U.FL-R-SMT-1_Vertical
aurabip_routed_PCB

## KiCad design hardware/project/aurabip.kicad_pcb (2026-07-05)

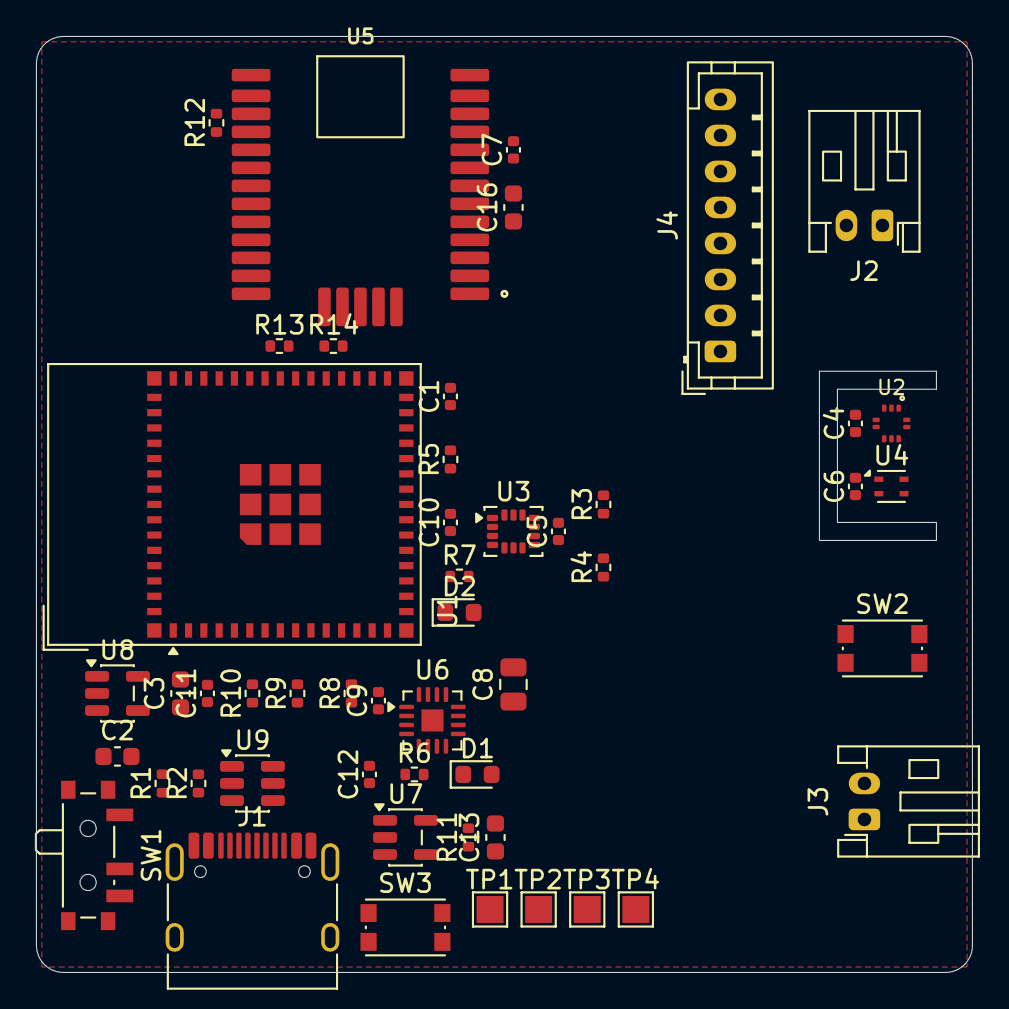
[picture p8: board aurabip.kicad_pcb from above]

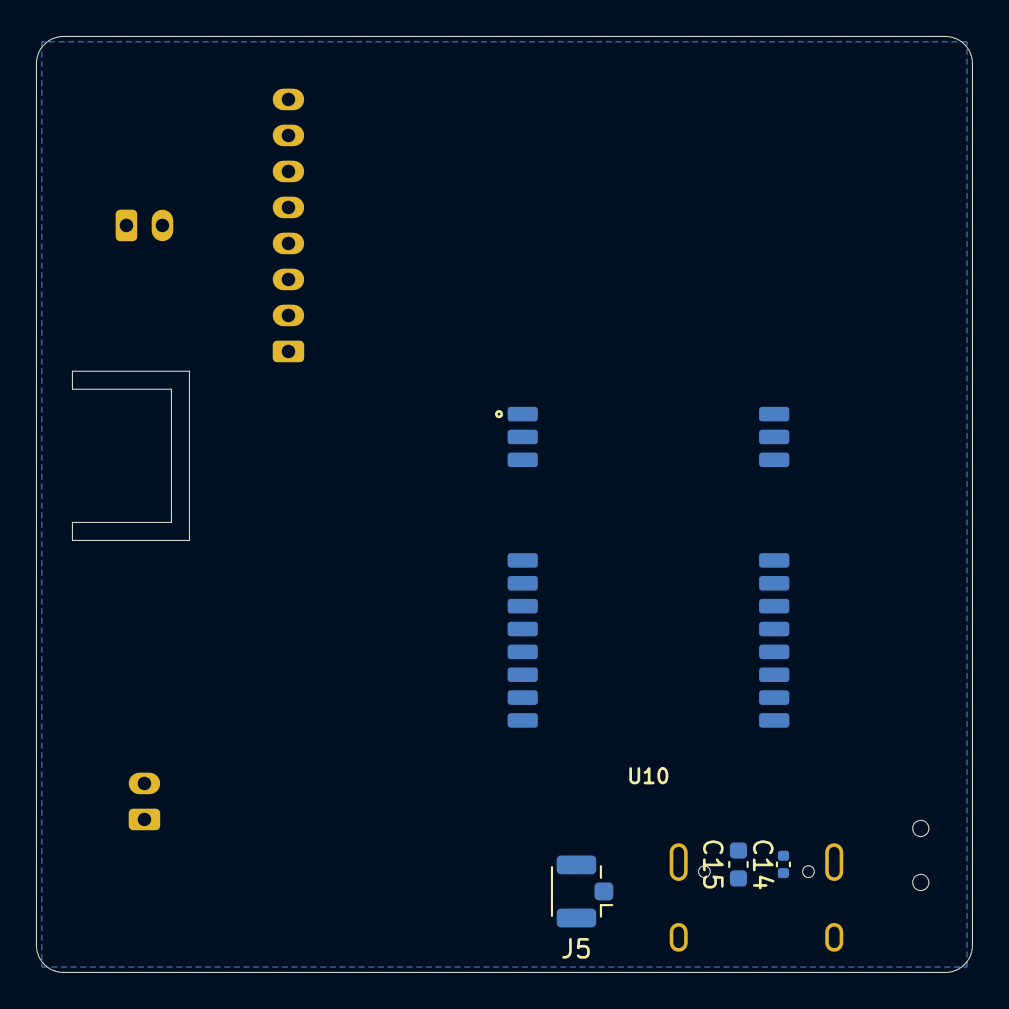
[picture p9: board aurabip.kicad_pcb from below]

Board: 4 copper layers, 52.0 x 52.0 mm, 54 parts (4 on the bottom side), 48 nets, no tracks yet.

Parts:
C1, C4, C5, C6, C7, C9, C11, C12, C14: 100n; C_0402_1005Metric
C2, C3, C15, C16: 10u; C_0603_1608Metric
C8: 22u; C_0805_2012Metric
C10: 1u; C_0402_1005Metric
C13: 4.7u; C_0603_1608Metric
D1: CHG; LED_0603_1608Metric
D2: STATUS; LED_0603_1608Metric
J1: USB-C; USB_C_Receptacle_HRO_TYPE-C-31-M-12
J2: AKKU; JST_PH_S2B-PH-K_1x02_P2.00mm_Horizontal
J3: SPEAKER; JST_PH_S2B-PH-K_1x02_P2.00mm_Horizontal
J4: OLED SPI; JST_PH_B8B-PH-K_1x08_P2.00mm_Vertical
J5: u.FL 868; U.FL_Hirose_U.FL-R-SMT-1_Vertical
R1, R2: 5.1k; R_0402_1005Metric
R3, R4: 4.7k; R_0402_1005Metric
R5: 10k; R_0402_1005Metric
R6, R7, R13: 1k; R_0402_1005Metric
R8: 100k; R_0402_1005Metric
R9, R10: 1M; R_0402_1005Metric
R11, R14: 2k; R_0402_1005Metric
R12: 0R; R_0402_1005Metric
SW1: EIN/AUS; SW_SPDT_PCM12
SW2: RESET; SW_Push_1P1T_NO_CK_KMR2
SW3: BOOT; SW_Push_1P1T_NO_CK_KMR2
TP1: IO33; TestPoint_Pad_1.5x1.5mm
TP2: IO34; TestPoint_Pad_1.5x1.5mm
TP3: IO35; TestPoint_Pad_1.5x1.5mm
TP4: IO36; TestPoint_Pad_1.5x1.5mm
U1: ESP32-S3-MINI-1; ESP32-S3-MINI-1_compact
U2: BMP581; BMP581_LGA-10_2x2mm
U3: LSM6DSO32; LGA-14_3x2.5mm_P0.5mm_LayoutBorder3x4y
U4: SHT40; Sensirion_DFN-4_1.5x1.5mm_P0.8mm_SHT4x_NoCentralPad
U5: L96; Quectel_L96
U6: MAX98357A; TQFN-16-1EP_3x3mm_P0.5mm_EP1.23x1.23mm
U7: MCP73831; SOT-23-5
U8: AP2112K-3.3; SOT-23-5
U9: USBLC6; SOT-23-6
U10: E22-900M22S; E22_900M22S

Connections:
+3V3: C1.1, C3.1, C4.1, C5.1, C6.1, C7.1, C14.1, C15.1, C16.1, J4.1, R3.1, R4.1, R5.1, R8.1, U1.3, U2.1, U2.5, U2.6, U2.10, U3.5, U3.8, U3.12, U4.3, U5.8, U5.9, U8.5, U10.9
AMP_SD: R8.2, U1.11, U6.4
BTN_BOOT: SW3.1, U1.4
CC1: J1.A5, R1.1
CC2: J1.B5, R2.1
CHG_LED_A: D1.2, R6.2
CHG_STAT: D1.1, U7.1
ESP_EN: C10.1, R5.2, SW2.1, U1.45
GND: C1.2, C2.2, C3.2, C4.2, C5.2, C6.2, C7.2, C8.2, C9.2, C10.2, C11.2, C12.2, C13.2, C14.2, C15.2, C16.2, D2.1, J1.A1, J1.A12, J1.B1, J1.B12, J1.SH, J2.2, J4.2, J5.2, R1.2, R2.2, R10.2, R11.2, R14.2, SW1.3, SW2.2, SW3.2, U1.1, U1.2, U1.42, U1.43, U1.46, U1.47, U1.48, U1.49, U1.50, U1.51, U1.52, U1.53, U1.54, U1.55, U1.56, U1.57, U1.58, U1.59, U1.60, U1.61, U1.62, U1.63, U1.64, U1.65, U2.3, U2.8, U2.9, U3.1, U3.6, U3.7, U4.4, U5.4, U5.5, U5.10, U5.11, U5.12, U5.13, U5.14, U5.15, U5.18, U5.19, U5.21, U5.22, U5.27, U5.31, U6.3, U6.11, U6.15, U6.17, U7.2, U8.2, U9.2, U10.1, U10.2, U10.3, U10.4, U10.5, U10.10, U10.11, U10.12, U10.20, U10.22
GNSS_RXD: R13.1, U1.22
GNSS_RXD_DIV: R13.2, R14.1, U5.26
GNSS_TXD: U1.21, U5.25
I2C_SCL: R4.2, U1.13, U2.2, U3.13, U4.2
I2C_SDA: R3.2, U1.12, U2.4, U3.14, U4.1
I2S_BCLK: U1.8, U6.16
I2S_DOUT: U1.10, U6.1
I2S_LRCK: U1.9, U6.14
IMU_INT1: U1.14, U3.4
L96_RFIN: R12.2, U5.17
L96_RFOUT: R12.1, U5.16
LDO_EN: SW1.2, U8.3
LED2_A: D2.2, R7.2
LED_STATUS: R7.1, U1.6
LORA_ANT: J5.1, U10.21
LORA_BUSY: U1.18, U10.14
LORA_DIO1: U1.7, U10.13
LORA_NSS: U1.25, U10.19
LORA_RST: U1.19, U10.15
LORA_RXEN: U1.33, U10.6
LORA_TXEN: U1.20, U10.7
OLED_CS: J4.5, U1.28
OLED_DC: J4.6, U1.29
OLED_RST: J4.7, U1.31
PROG: R11.1, U7.5
SPI2_MISO: U1.17, U10.16
SPI2_MOSI: J4.3, U1.15, U10.17
SPI2_SCK: J4.4, U1.16, U10.18
SPK_N: J3.2, U6.10
SPK_P: J3.1, U6.9
TP_IO38: TP1.1, U1.34
TP_IO40: TP2.1, U1.36
TP_IO41: TP3.1, U1.37
TP_IO42: TP4.1, U1.38
USB_DN: J1.A7, J1.B7, U1.23, U9.1, U9.6
USB_DP: J1.A6, J1.B6, U1.24, U9.3, U9.4
VBAT: C2.1, C8.1, C9.1, C13.1, J2.1, R9.1, SW1.1, U6.7, U6.8, U7.3, U8.1
VBAT_SENSE: C11.1, R9.2, R10.1, U1.5
VBUS: C12.1, J1.A4, J1.A9, J1.B4, J1.B9, R6.1, U7.4, U9.5

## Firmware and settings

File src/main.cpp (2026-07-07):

// AuraBip — Hauptprogramm
// © 2026 KIE Engineering. Proprietär.
//
// Tasks:
//   Core 1: Sensorik (IMU 200 Hz predict, Baro 50 Hz update) — harte Latenz
//   Core 0: BLE (5 Hz LK8EX1 + NMEA), Display (5 Hz), Audio-Render, FANET-TX
//
// Boards:
//   Heltec V3/V4 (silent/audio): Sensorik SIMULIERT (sensors_stub.cpp)
//   Serienboard (series/series_vision): echte Treiber (sensors_series.cpp),
//     GNSS-Parser, FANET-Tracking (Typ 1, nur TX), I2S-Audio + Ansagen

#include <Arduino.h>
#include <Wire.h>
#include <esp_task_wdt.h>
#include <esp_idf_version.h>
#include "config.h"
#include "vario.h"
#include "sensors.h"
#include "gnss.h"
#include "ble_link.h"
#include "display.h"
#ifdef VARIANT_AUDIO
#include "audio.h"
AudioEngine audio;
#endif
#ifdef BOARD_SERIES
#include <SPI.h>
#include "fanet_tx.h"
FanetTx fanetTx;
#endif

VarioKF  kf;
BleLink  ble;
Display  disp;
NmeaParser gnss;
HardwareSerial GnssSerial(1);

volatile float g_vario = 0, g_alt = 0;
static float g_lastTemp = 15.0f;

// --- Sensor-Task: Kern des Varios ---
void sensorTask(void*) {
  esp_task_wdt_add(NULL);
  kf.reset(pressureToAlt(sensors::readPressurePa()));
  uint32_t lastBaro = 0;
  TickType_t wake = xTaskGetTickCount();
  for (;;) {
    esp_task_wdt_reset();
    float ax, ay, az;
    sensors::readAccel(ax, ay, az);
    kf.predict(verticalAccelApprox(ax, ay, az), 1.0f / IMU_RATE_HZ);

    if (millis() - lastBaro >= 1000 / BARO_RATE_HZ) {
      lastBaro = millis();
      float p = sensors::readPressurePa();
      if (p > 0) kf.update(pressureToAlt(p));
    }
    g_vario = kf.vario();
    g_alt   = kf.altitude();
    vTaskDelayUntil(&wake, pdMS_TO_TICKS(1000 / IMU_RATE_HZ));
  }
}

// --- GNSS: Zeilen parsen (RMC+GGA) + roh per BLE durchreichen ---
static void pumpGnss() {
  while (GnssSerial.available()) {
    if (gnss.feed((char)GnssSerial.read())) {
      const char* l = gnss.line();
      if (strncmp(l, "$G", 2) == 0 && (strstr(l, "RMC") || strstr(l, "GGA"))) {
        ble.sendLine(l); ble.sendLine("\r\n");
      }
    }
  }
}

#ifdef BOARD_SERIES
// --- Batterie: Teiler 1M/1M -> VBAT/2 an ADC ---
static int batteryPct() {
  uint32_t mv = analogReadMilliVolts(PIN_VBAT_ADC) * 2;
  float pct = (mv - 3300) / (4200.0f - 3300.0f) * 100.0f;  // linear, grob
  if (pct < 0) pct = 0; if (pct > 100) pct = 100;
  return (int)pct;
}

// --- Flugerkennung (Hysterese): Fix + Speed ---
static bool flying() {
  static bool fly = false;
  static uint32_t slowSince = 0;
  bool fresh = gnss.data.fix && (millis() - gnss.data.lastFixMs < 5000);
  if (!fly) {
    if (fresh && gnss.data.speed_kmh > FLIGHT_START_KMH) fly = true;
  } else {
    if (fresh && gnss.data.speed_kmh > FLIGHT_STOP_KMH) slowSince = 0;
    else if (!slowSince) slowSince = millis();
    else if (millis() - slowSince > FLIGHT_STOP_HOLD_MS) { fly = false; slowSince = 0; }
  }
  return fly;
}
#endif

void setup() {
  Serial.begin(115200);
  Wire.begin(PIN_I2C_SDA, PIN_I2C_SCL, 400000);

#if ESP_IDF_VERSION >= ESP_IDF_VERSION_VAL(5, 0, 0)
  esp_task_wdt_config_t wdt = { .timeout_ms = 10000, .idle_core_mask = 0, .trigger_panic = true };
  esp_task_wdt_init(&wdt);
#else
  esp_task_wdt_init(10, true);  // IDF 4.x (Arduino-Core 2.x): Sekunden-API
#endif
  esp_task_wdt_add(NULL);

#ifdef BOARD_SERIES
  pinMode(PIN_LED, OUTPUT);
  digitalWrite(PIN_LED, HIGH);            // an bis Setup durch
  pinMode(PIN_BTN, INPUT_PULLUP);
  pinMode(PIN_LORA_NSS, OUTPUT); digitalWrite(PIN_LORA_NSS, HIGH);
  pinMode(PIN_OLED_CS, OUTPUT);  digitalWrite(PIN_OLED_CS, HIGH);
  SPI.begin(PIN_SPI_SCK, PIN_SPI_MISO, PIN_SPI_MOSI);   // geteilter SPI2-Bus
#endif

  disp.begin();
  if (!sensors::init()) Serial.println("[ERR] Sensor-Init — I2C-Map prüfen");
  ble.begin(DEVICE_NAME);
  GnssSerial.begin(GNSS_BAUD, SERIAL_8N1, PIN_GNSS_RX, PIN_GNSS_TX);
#ifdef VARIANT_AUDIO
  audio.begin();
#endif
#ifdef BOARD_SERIES
  if (!fanetTx.begin()) Serial.println("[ERR] FANET-Init — SX1262 prüfen");
  digitalWrite(PIN_LED, LOW);
#endif

  xTaskCreatePinnedToCore(sensorTask, "sensor", 4096, nullptr, 10, nullptr, 1);
}

void loop() {
  esp_task_wdt_reset();
  pumpGnss();

  static uint32_t lastTx = 0, lastDisp = 0, lastTemp = 0;
  uint32_t now = millis();

  if (now - lastTemp > 5000) { lastTemp = now; g_lastTemp = sensors::readTempC(); }

  int batt = -1;
#ifdef BOARD_SERIES
  batt = batteryPct();

  // FANET-Tracking: alle 5 s, nur im Flug (Doppel-Sicherung: Flag + Flug)
  static uint32_t lastFanet = 0;
  bool fanetActive = false;
  if (FANET_TX_ENABLED && fanetTx.ok && flying() &&
      now - lastFanet >= FANET_TX_INTERVAL_MS) {
    lastFanet = now;
    fanetActive = fanetTx.sendTracking(gnss.data.lat, gnss.data.lon,
                                     gnss.data.alt_m, gnss.data.speed_kmh,
                                     g_vario, gnss.data.course_deg);
  }
  disp.status(gnss.data.sats, fanetActive || (now - lastFanet < 2 * FANET_TX_INTERVAL_MS && lastFanet));
#endif

  if (now - lastTx >= 1000 / LK8EX1_RATE_HZ) {
    lastTx = now;
    ble.sendLK8EX1(sensors::readPressurePa(), g_alt, g_vario, g_lastTemp, batt);
  }
  if (now - lastDisp >= 200) {
    lastDisp = now;
    disp.flight(g_vario, g_alt, gnss.data.speed_kmh, ble.connected(), gnss.data.fix);
  }
#ifdef VARIANT_AUDIO
  audio.render(g_vario);
#endif
  delay(2);
}

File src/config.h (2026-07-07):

// AuraBip — Konfiguration
// © 2026 KIE Engineering. Proprietär.
#pragma once

#define DEVICE_NAME       "AuraBip"

// I2C-Adressen (beide Boards gleich)
#define I2C_ADDR_BMP581   0x47
#define I2C_ADDR_LSM6     0x6A
#define I2C_ADDR_SHT40    0x44

#ifdef BOARD_SERIES
// ============================================================================
// Serienboard v0.1 — ESP32-S3-MINI-1 (Referenz: hardware/PINMAP.md)
// ============================================================================

// --- I2C (ein Bus: BMP581 + LSM6DSO32 + SHT40) ---
#define PIN_I2C_SDA       8
#define PIN_I2C_SCL       9
#define PIN_IMU_INT       10   // LSM6DSO32 INT1 (Tap/Data-Ready, v0.1 ungenutzt)

// --- Audio: I2S -> MAX98357A ---
#define PIN_I2S_BCLK      4
#define PIN_I2S_LRCK      5
#define PIN_I2S_DOUT      47   // Routing-Umzug 2026-07-06: IO6 -> IO47 (s. PINMAP.md)
#define PIN_AMP_SD        7    // high = Amp an (100k-Pullup an 3V3)

// --- GNSS: Quectel L96 an UART1 ---
#define PIN_GNSS_RX       17   // <- L96 TXD
#define PIN_GNSS_TX       18   // -> L96 RXD
#define GNSS_BAUD         9600

// --- LoRa: E22-900M22S (SX1262) an SPI2, geteilt mit OLED ---
#define PIN_SPI_SCK       12
#define PIN_SPI_MOSI      11
#define PIN_SPI_MISO      13
#define PIN_LORA_NSS      21
#define PIN_LORA_DIO1     3
#define PIN_LORA_BUSY     14
#define PIN_LORA_RST      15
#define PIN_LORA_TXEN     16
#define PIN_LORA_RXEN     37

// --- OLED SSD1327 (Variante vision, geteilter SPI2-Bus) ---
#define PIN_OLED_CS       33
#define PIN_OLED_DC       34
#define PIN_OLED_RST      35

// --- Sonstiges ---
#define PIN_VBAT_ADC      1    // Teiler 1M/1M -> VBAT/2
#define PIN_LED           2    // Status-LED, aktiv high
#define PIN_BTN           0    // BOOT/USER-Taster (aktiv low)

#else
// ============================================================================
// Heltec V3/V4 Prototyp — Sensorik simuliert (sensors_stub.cpp)
// ============================================================================

// --- I2C (⚠️ VERIFY Pins am V4-Schema; V3: SDA=17 SCL=18 fürs OLED-Bus) ---
#define PIN_I2C_SDA       41   // externer Sensorbus (getrennt vom OLED-Bus möglich)
#define PIN_I2C_SCL       42

// --- OLED (onboard, eigener Bus beim Heltec) ---
#define PIN_OLED_SDA      17
#define PIN_OLED_SCL      18
#define PIN_OLED_RST      21
#define PIN_VEXT          36   // OLED/Peripherie-Versorgung (LOW = an) ⚠️ VERIFY V4

// --- GNSS (SH1.25-8P) ⚠️ VERIFY Pinout aus V4-Doku (T2) ---
#define PIN_GNSS_RX       33
#define PIN_GNSS_TX       34
#define GNSS_BAUD         9600

// --- Audio-Variante (nur bei -D VARIANT_AUDIO) ---
#define PIN_I2S_BCLK      6
#define PIN_I2S_LRCK      5
#define PIN_I2S_DOUT      7

#endif // BOARD_SERIES

#define AUDIO_SAMPLE_RATE 16000

// --- Vario-Filter ---
#define BARO_RATE_HZ      50
#define IMU_RATE_HZ       200
#define KF_ACCEL_NOISE    0.3f    // m/s² Prozessrauschen (tunen im Flug)
#define KF_BARO_NOISE     0.35f   // m Messrauschen BMP581 (tunen)

// --- Ton-Engine (audio) ---
#define TONE_CLIMB_ON_MS_BASE   350
#define TONE_BASE_FREQ_HZ       600
#define TONE_FREQ_PER_MS        120   // Hz pro m/s Steigen
#define SINK_ALARM_MS           -3.5f // Dauerton unterhalb

// --- BLE ---
#define LK8EX1_RATE_HZ    5

// --- FANET (nur Serienboard, nur TX) ---
#define FANET_TX_ENABLED        1
#define FANET_TX_INTERVAL_MS    5000
#define FANET_TX_DBM            14
#define FANET_TCXO_VOLT         1.8f  // E22-900M22S: TCXO an DIO3, 1.8 V
#define FANET_FREQ_MHZ          868.2f
#define FANET_AIRCRAFT_TYPE     1     // 1 = Paraglider
// Flugerkennung: GPS-Fix + Speed-Schwelle mit Hysterese
#define FLIGHT_START_KMH        10.0f
#define FLIGHT_STOP_KMH         5.0f
#define FLIGHT_STOP_HOLD_MS     60000

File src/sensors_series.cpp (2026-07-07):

// AuraBip — Echte Sensortreiber fürs Serienboard (raw I2C, keine Fremdlibs)
// © 2026 KIE Engineering. Proprietär.
//
// BMP581-Zugriff portiert aus dem Aura-Krücke-Projekt (eigener Code,
// C:\Users\Ivo\aura_kruecke\src\main.cpp rawBMP581Pressure); Registerwerte
// gegen das Bosch-Datenblatt bzw. bmp5_defs.h verifiziert.
// SHT40: Sensirion-Kommando 0xFD (High Precision), Formeln lt. Datenblatt.
// LSM6DSO32: ST-Registersatz (WHO_AM_I 0x6C), 208 Hz / ±8 g.

#ifdef BOARD_SERIES
#include <Arduino.h>
#include <Wire.h>
#include "config.h"
#include "sensors.h"

namespace sensors {

// --- I2C-Helfer --------------------------------------------------------------
// Mutex: Sensor-Task (200 Hz, Core 1) und loop() (LK8EX1/SHT40) teilen sich
// den Bus — jede Transaktion ist gelockt, die SHT40-Messwartezeit NICHT.
static SemaphoreHandle_t s_busMtx = nullptr;

struct BusLock {
  BusLock()  { if (s_busMtx) xSemaphoreTake(s_busMtx, portMAX_DELAY); }
  ~BusLock() { if (s_busMtx) xSemaphoreGive(s_busMtx); }
};

static bool writeReg(uint8_t addr, uint8_t reg, uint8_t val) {
  BusLock lock;
  Wire.beginTransmission(addr);
  Wire.write(reg); Wire.write(val);
  return Wire.endTransmission() == 0;
}

static bool readRegs(uint8_t addr, uint8_t reg, uint8_t* buf, size_t len) {
  BusLock lock;
  Wire.beginTransmission(addr);
  Wire.write(reg);
  if (Wire.endTransmission(false) != 0) return false;
  if (Wire.requestFrom(addr, (uint8_t)len) != len) return false;
  for (size_t i = 0; i < len; i++) buf[i] = Wire.read();
  return true;
}

// --- BMP581 (0x47) ------------------------------------------------------------
// Register: CHIP_ID 0x01 (=0x50), OSR_CONFIG 0x36, ODR_CONFIG 0x37,
//           Druck 0x20..0x22 (24 bit LE, /64 = Pa)
static bool bmpInit() {
  uint8_t id = 0;
  if (!readRegs(I2C_ADDR_BMP581, 0x01, &id, 1) || id != 0x50) return false;
  // OSR_CONFIG: press_en (bit6) | osr_p 16x (0x04<<3) | osr_t 4x (0x02)
  if (!writeReg(I2C_ADDR_BMP581, 0x36, 0x40 | (0x04 << 3) | 0x02)) return false;
  // ODR_CONFIG: odr 50 Hz (0x0F<<2) | pwr_mode NORMAL (0x01)
  if (!writeReg(I2C_ADDR_BMP581, 0x37, (0x0F << 2) | 0x01)) return false;
  delay(20);  // erste Messung
  return true;
}

float readPressurePa() {
  uint8_t d[3];
  if (!readRegs(I2C_ADDR_BMP581, 0x20, d, 3)) return -1.0f;
  int32_t raw = (int32_t)d[0] | ((int32_t)d[1] << 8) | ((int32_t)d[2] << 16);
  if (raw & 0x800000) raw |= 0xFF000000;
  return (float)raw / 64.0f;  // Pa
}

// --- LSM6DSO32 (0x6A) ----------------------------------------------------------
// WHO_AM_I 0x0F (=0x6C), CTRL1_XL 0x10, CTRL3_C 0x12, OUTX_L_A 0x28
// DSO32-FS_XL-Codierung (bits 3:2): 00=±4g 01=±32g 10=±8g 11=±16g
static bool imuInit() {
  uint8_t id = 0;
  if (!readRegs(I2C_ADDR_LSM6, 0x0F, &id, 1) || id != 0x6C) return false;
  writeReg(I2C_ADDR_LSM6, 0x12, 0x44);            // CTRL3_C: BDU | IF_INC
  // CTRL1_XL: ODR 208 Hz (0101<<4) | FS ±8g (10<<2)
  return writeReg(I2C_ADDR_LSM6, 0x10, (0x05 << 4) | (0x02 << 2));
}

void readAccel(float& ax, float& ay, float& az) {
  uint8_t d[6];
  if (!readRegs(I2C_ADDR_LSM6, 0x28, d, 6)) { ax = ay = 0; az = 9.81f; return; }
  int16_t x = (int16_t)(d[0] | (d[1] << 8));
  int16_t y = (int16_t)(d[2] | (d[3] << 8));
  int16_t z = (int16_t)(d[4] | (d[5] << 8));
  const float k = 0.244e-3f * 9.80665f;  // ±8g: 0.244 mg/LSB -> m/s²
  ax = x * k; ay = y * k; az = z * k;
}

// --- SHT40 (0x44) ---------------------------------------------------------------
static float g_temp = 15.0f, g_rh = 50.0f;

static bool shtMeasure() {
  {
    BusLock lock;
    Wire.beginTransmission(I2C_ADDR_SHT40);
    Wire.write(0xFD);                     // Measure High Precision
    if (Wire.endTransmission() != 0) return false;
  }
  delay(10);                              // Messzeit lt. Datenblatt (max 8.3 ms)
  uint8_t d[6];
  {
    BusLock lock;
    if (Wire.requestFrom((uint8_t)I2C_ADDR_SHT40, (uint8_t)6) != 6) return false;
    for (int i = 0; i < 6; i++) d[i] = Wire.read();
  }
  uint16_t t_raw = (d[0] << 8) | d[1];
  uint16_t h_raw = (d[3] << 8) | d[4];
  g_temp = -45.0f + 175.0f * (float)t_raw / 65535.0f;
  g_rh   =  -6.0f + 125.0f * (float)h_raw / 65535.0f;
  if (g_rh > 100) g_rh = 100; if (g_rh < 0) g_rh = 0;
  return true;
}

float readTempC()    { shtMeasure(); return g_temp; }
float readHumidity() { return g_rh; }   // aus letzter readTempC()-Messung

// --- Init ------------------------------------------------------------------------
bool init() {
  if (!s_busMtx) s_busMtx = xSemaphoreCreateMutex();
  bool bmp = bmpInit();
  bool imu = imuInit();
  bool sht = shtMeasure();
  Serial.printf("[I2C] BMP581  0x%02X: %s\n", I2C_ADDR_BMP581, bmp ? "OK" : "FEHLT");
  Serial.printf("[I2C] LSM6DSO32 0x%02X: %s\n", I2C_ADDR_LSM6, imu ? "OK" : "FEHLT");
  Serial.printf("[I2C] SHT40   0x%02X: %s\n", I2C_ADDR_SHT40, sht ? "OK" : "FEHLT");
  return bmp && imu && sht;
}

} // namespace sensors
#endif // BOARD_SERIES

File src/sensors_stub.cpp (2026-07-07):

// AuraBip — Sensor-Stub (Platzhalter bis T2 die echten Treiber portiert)
// © 2026 KIE Engineering. Proprietär.
//
// init() probt die erwarteten I2C-Adressen real (zeigt also echte
// Verkabelungsfehler). Die Messwerte sind SIMULIERT: Normaldruck mit
// leichter Sinus-Welle (~±0.5 m/s Vario zum Testen von Display/BLE/Ton),
// Accel = 1 g ruhend, Temp = 15 °C. T2 ersetzt diese Datei komplett.

#ifndef BOARD_SERIES
#include <Arduino.h>
#include <Wire.h>
#include <math.h>
#include "config.h"
#include "sensors.h"

namespace sensors {

static bool probe(uint8_t addr) {
  Wire.beginTransmission(addr);
  return Wire.endTransmission() == 0;
}

bool init() {
  struct { uint8_t addr; const char* name; } chips[] = {
    { I2C_ADDR_BMP581, "BMP581" },
    { I2C_ADDR_LSM6,   "LSM6DSO32" },
    { I2C_ADDR_SHT40,  "SHT40" },
  };
  bool all = true;
  for (auto& c : chips) {
    bool ok = probe(c.addr);
    Serial.printf("[I2C] %-10s 0x%02X: %s\n", c.name, c.addr, ok ? "OK" : "FEHLT");
    all &= ok;
  }
  if (!all) Serial.println("[I2C] STUB aktiv — Messwerte sind simuliert!");
  return all;
}

float readPressurePa() {
  // Normaldruck + langsame Welle: ~±4 m Hub, Periode 30 s -> sichtbares Vario
  return 101325.0f + 50.0f * sinf(millis() * (2.0f * PI / 30000.0f));
}

void readAccel(float& ax, float& ay, float& az) {
  ax = 0.0f; ay = 0.0f; az = 9.81f;   // ruhend, z nach oben
}

float readTempC() {
  return 15.0f;
}

float readHumidity() {
  return 50.0f;
}

} // namespace sensors
#endif // !BOARD_SERIES

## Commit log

2026-07-03 feat: AuraBip Scaffold v0.1 — BLE-Vario (Heltec V4)
    Scaffold aus aurabip-scaffold-v0.1.zip plus Build-Fixes:
    - Watchdog-API IDF-4/5-Guard (Arduino-Core 2.x nutzt Sekunden-API)
    - sensors_stub.cpp: I2C-Probe echt, Messwerte simuliert (bis T2)
    - audio.h: float-Modulo-Fehler in Piep-Kadenz behoben
    Beide Varianten (silent/audio) bauen.
    [audio.h, config.h, display.h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]
2026-07-05 feat(hardware): Serien-Board v0.1 — 52x52, FANET, Sensor-Insel, 1.32-OLED
    - BOM/PINMAP/README: ESP32-S3-MINI-1, BMP581, LSM6DSO32, SHT40, L96,
    MAX98357A, E22-900M22S (FANET-TX, Pflicht 2027), ME6217-LDO 800mA
    - Generatoren: Schema (ERC 0 Fehler) + PCB (52x52, 4 Lagen, Platzierung
    kollisionsfrei) komplett aus Python, eine Quelle der Wahrheit
    - Sensor-Insel: C-Fraesgraben um BMP581+SHT40 gegen Eigenerwaermung
    - E22 + u.FL auf Rueckseite, ESP32-Kompakt-Footprint (Espressif-Keepout
    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
    [aurabip.kicad_pcb, aurabip.kicad_sch, aurabip_preview.kicad_pcb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]
2026-07-05 fix(hardware): alle kritischen Pinouts gegen Datenblaetter verifiziert
    Web-Recherche gegen Originalquellen (Ebyte Manual v1.3, Quectel HW
    Design V1.4, ADI Rev 7, ST Rev 1) — drei von vier Annahmen waren falsch:
    - E22-900M22S: 14x20/Pitch 1.27 statt 16x26/2.2, Pin-Map komplett neu
    - L96: LCC-31 statt 12 Pads; RF-Bruecke R12 (RF_OUT->RF_IN, sonst kein
    GPS!), RXD-Pegelteiler R13/R14 (VIHmax 3.1V), C16, Antennen-Keepout
    - MAX98357A: TQFN-Pinout neu (Pin 8 war VDD, nicht GND!), EP1.23-Footprint
    - LSM6DSO32: Pinout bestaetigt, ST-Footprint statt Bosch (0.1mm-Versatz)
    Dazu: Gehaeuse-Generator fuer Fusion 360 (hardware/fusion/, Varianten
    audio/vision, Akku 504050, K-28-WP-Sitz, Antennen-Nische,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
    [aurabip-bom.csv, aurabip.kicad_pcb, aurabip.kicad_sch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]
2026-07-05 feat(route): deterministischer Rest-Router v4 + Gehaeuse v2 (Akustik)
    - handroute4: exakte Rechteck-Kollisionspruefung (Pad-AABBs),
    Segment-Schnitttest (Kreuzungs-Bug behoben), Via-Routing F->B,
    Diagonal-/Dogleg-Kandidaten, Multi-Via-Spots, GND-Offset-Hookup;
    laeuft als LETZTER Pipeline-Schritt (kein FreeRouting-Roundtrip
    mehr danach — der SES-Import verwirft sonst Handrouten)
    - LoRa-Bus (ESP<->E22 ueber Rueckseite) wird deterministisch gelegt
    - Fusion-Gehaeuse v2: root.name-Fix, geschlossene Lautsprecher-
    Rueckkammer + Trichterfront + optionaler Reflex-Kanal (PORT),
    Antennen-Nische vertikal / optional SMA-Stummel (ANT_STUB),
    Akku 504050, J3 90 Grad gedreht (Ivo)
    Co-Authored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
    [aurabip.kicad_pcb, aurabip_routed.kicad_pcb]
2026-07-05 feat: News-Seite Juli 2026 + Gehaeuse v3 + Routing-Basis bereinigt
    - docs/news: fertige Projekt-News-Seite (Renderings eingebettet,
    Explosionsansicht, Status) fuer die Website
    - Gehaeuse v3: 5mm Wand, Nut/Feder-Dichtsitz, 4x M2-Inbus + Inserts,
    geschlossener Reflexkanal bis durch die Aussenwand, USB-/Schalter-
    Taschen, Display-Fenster mit exakten Waveshare-Massen (34.3x30.5,
    Glas-Versatz -0.98mm)
    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
    [aurabip.kicad_pcb, aurabip_routed.kicad_pcb]
2026-07-05 feat(route): Platine FERTIG — DRC 0 Verstoesse, 0 unverbunden
    Eigener A*-Maze-Router (maze_router.py): 0.1-mm-Raster, 2 Lagen,
    Via-Uebergaenge, exaktes Hindernismodell (Pads/Tracks/Vias/Moat/
    Keepouts/NPTH), --narrow (5 mil), --ortho (keine Eckenschnitte),
    --rip (Rip-up&Reroute), --pairs, Via-in-Pad-Rettung mit praeziser
    Geometriepruefung, systematische Insel-Heilung (Waisen-Pours).
    Bugs auf dem Weg: A*-f/g-Verwechslung, SWIG-__eq__, Diagonal-
    Eckenschnitte, Splice-Diagonalen. I2S_DOUT per GPIO-Matrix auf
    IO47 verlegt (IO6-Region war zugebaut) — Schema/Firmware-Doku folgt.
    Fertigungspaket: Gerber-ZIP, Bohrdaten, Pick&Place beidseitig,
    STEP-Modell. VOR BESTELLUNG: BOM-CSV neu generieren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
    [aurabip.kicad_sch, aurabip.step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]
2026-07-05 fix: J3 Oeffnung zur Board-Mitte (DRC 0/0) + ADS-L-Korrektur in News/BOM/README
    Keine 'Pflicht 2027'-Behauptung mehr — Standard-Kandidat ADS-L,
    Hardware GFSK-faehig = ADS-L-ready per FW-Update. News-Seite mit
    finalen Board-Renderings neu gebaut, Gruppenchat-Uebergabe an
    @Webseite geschrieben.
    [aurabip_routed.kicad_pcb]
2026-07-05 feat(news): Gehaeuse-Explosionsschnitt massstaeblich aus CAD-Parametern
    build_case_svg.py liest den P-Block aus aurabip_case.py und generiert
    die Schnittzeichnung (Deckel mit Trichter/Boss/Reflexkanal/Feder,
    Lautsprecher, Kammerdeckel, Platine+E22, Akku, Basis mit Nut/Insert/
    Antennen-Nische) — eine Quelle der Wahrheit statt Freihand.
    News-Paket zusaetzlich in den Team-Drive kopiert (Webseiten-Uebergabe).
2026-07-05 feat(emv): Review umgesetzt — Board-RF eliminiert, SPK-Paar enger
    EMV-Review (Ivo) Punkt 3 nicht repariert sondern eliminiert: die
    34-mm-ANT-Leitung (lag nach Modul-Flip quer ueber halbes Board, 15
    Nachbarsignale) faellt weg — Flexantenne steckt DIREKT auf die
    IPX-Buchse des E22-Moduls. J5 + LORA_ANT komplett entfernt
    (Schema ERC 0, Board DRC 0/0). SPK_P neu als Ortho-Route neben
    SPK_N (Schleifenflaeche runter). Audit bestaetigt: Innenlagen
    tragen NULL Signale — GND/3V3-Planes durchgehend.
    [aurabip.kicad_sch, aurabip_routed.kicad_pcb]
2026-07-06 build: Fertigungspaket final (Gerber/Bohr/PnP/BOM vom Endstand)
    [aurabip-bom.csv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]
2026-07-06 docs: PCBWay-Bestellparameter + BOM-Beschreibungen englisch
    [aurabip-bom.csv]
2026-07-06 chore(bom): englische Beschreibungen fuer PCBWay-Bestueckung; U10/J2-J4 Vermerke aktualisiert (beide Seiten werden bestueckt)
    [aurabip-bom.csv]
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2026-07-07 feat(firmware): Serien-Board-Support - echte Treiber, FANET-TX, I2S-Audio mit Sprach-Framework
    - [env:series]/[env:series_vision]: ESP32-S3-MINI-1 (8MB, USB-CDC), Custom-Partitionen mit ~2.4MB LittleFS
    - Echte Sensortreiber (raw I2C): BMP581 50Hz, LSM6DSO32 208Hz/8g, SHT40; Bus-Mutex Sensor-Task vs. loop
    - Eigener NMEA-Parser (RMC+GGA, Checksumme) fuer Quectel L96
    - FANET-TX: lib/fanet aus WindBuddy uebernommen + Typ-1-Tracking-Encoder; RadioLib SX1262 (E22: TCXO 1.8V, RXEN/TXEN), 14dBm, alle 5s im Flug (Hysterese-Flugerkennung), nur TX
    - Audio: MAX98357A-I2S mit AMP_SD, Vario-Piepser + WAV-Sprach-Framework (LittleFS /voice, Prioritaets-Queue, speakWarning/speakInfo), tools/make_test_wav.py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
    [partitions_custom.csv]
2026-07-07 wip(pcb): Via-in-Pad - 20/35 sauber per Drag-Router verschoben (DRC 0/0)
    Selbstgebauter Verschiebe-Router (route/fix_via_in_pad.py): zieht Via +
    angebundene Track-Enden aus dem Pad (KiCad-Drag-Prinzip), F.Cu-Stub bindet
    das Pad neu an - Konnektivitaet konstruktiv erhalten. Rigoroses Kollisions-
    modell inkl. interner Fraeskontur + Bohrabstand. 15 Vias in dichten Modul-
    zonen noch offen (Folge-Commit).
    [aurabip_routed.kicad_pcb]
2026-07-07 wip(pcb): Via-in-Pad - 23/35 (GND-Stub-Handler ergaenzt), DRC 0/0
    [aurabip_routed.kicad_pcb]
2026-07-07 wip(pcb): Via-in-Pad 14 offen - U7.2 GND per Drag geloest, DRC 0/0
    [aurabip_routed.kicad_pcb]
2026-07-07 wip(pcb): Via-in-Pad 10 offen - Snug-Loeser (U7.2/U9.2/U4.1/U9.4/U1.23), DRC 0/0
    [aurabip_routed.kicad_pcb]
2026-07-07 wip(pcb): Via-in-Pad 9 offen - U5.31 GND redundant (F-Zone deckt Pad), Via geloescht, DRC 0/0
    [aurabip_routed.kicad_pcb]
2026-07-07 wip(pcb): Via-in-Pad 8 offen - U10.12 GND redundant, Via geloescht, DRC 0/0
    [aurabip_routed.kicad_pcb]
2026-07-07 wip(pcb): Via-in-Pad 6 offen - U10.10/U10.5 GND redundant, Vias geloescht, DRC 0/0
    [aurabip_routed.kicad_pcb]
2026-07-08 fix(pcb): letzte 6 Via-in-Pad weggeroutet - 0 in-pad, DRC 0/0, kein PCBWay-Fuellprozess noetig
    Reste (R4.2 SCL, U9.1 USB_DN, R2.1 CC2, U6.3/U6.11/U10.15 GND) off-pad
    geloest: GND per EP-Tie bzw. Off-pad-Stitch, Signal per lokalem Rip-and-
    Reroute (route/local_maze.py, A* wie maze_router). R2.1-CC2-Via war redundant
    (F-Pfad traegt) -> samt totem B-Zweig entfernt. Einzige In-Pad-Via: U1.61 EP.
    DRC --severity-error: 0 Fehler / 0 unconnected. Fab neu exportiert.
    [aurabip_routed-B_Cu.gbl, aurabip_routed-B_Mask.gbs, aurabip_routed-B_Paste.gbp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]
2026-07-16 feat(case): AuraPIP-Gehaeuse-Generator v4 - Display oben, Lautsprecher-Rundung
    Neuaufbau (aurapip_case.py, v3 bleibt als Referenz):
    - Display ganz nach oben; echter Einbau: Modul-Tasche + gedruckter
    Displayrahmen klemmt von hinten (2x M2.2 in Bosse), kein Kleben
    - Lautsprecher voll sichtbar (Oeffnung spk_d-3, optionale Schutzstege)
    in halbrunder Ausbuchtung an der Unterkante (spk_drop 12, bulge_wall 3)
    - ACHTUNG: Platine um 180 Grad gedreht einbauen (USB oben, Schalter
    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
2026-07-16 fix(case): Display-Befestigung gegen Waveshare-Masszeichnung verifiziert
    Offizielle Zeichnung 1_32inch_oled_module.pdf ausgemessen:
    - PCB 34.3x30.5x1.6, Glas 32.6x28.3 (nur ~1mm Rand), Stack 3.3,
    A.A 26.86x20.14, Stecker hinten 3.5 von Kante (+2.5 hinter PCB)
    - 4x M2-Loecher (29.10x24.90) liegen UNTER dem Glas -> Front-Bosse
    unmoeglich, Klemmrahmen ist die richtige Loesung (bestaetigt)
    - Rahmen: Stecker-Aussparung ergaenzt; Einbau Stecker nach UNTEN
    (Kabel in den Innenraum, glasbuendige Kante oben)
    - Fenster auf A.A+Luft vergroessert (28.5x21.7, off_y +1.2),
    disp_stack 4.1 aus echten Zeichnungswerten
2026-07-16 feat(case): Display-Montage kleben als Standard (sauber eingepasst)
    DISP_MOUNT-Schalter: kleben (Ivos Wahl) = Glas in enger Tasche
    (0.4 Spiel, 1.8 tief, Glas ganz versenkt -> PCB-Rand liegt an der
    Deckeldecke an, dort duenne Kleberaupe E6000/Silikon; nie das Glas
    kleben). rahmen = geschraubter Klemmrahmen bleibt als Option.
    Glas-Tasche nutzt die verifizierten Zeichnungswerte (32.6x28.3,
    Versatz -1.23 in Einbaulage Stecker unten).
2026-07-16 chore(case): v3-Generator ins Archiv - nur noch aurapip_case (v4) im Skript-Ordner
    Ivo bekam in Fusion das alte Design: aurabip_case (v3) und aurapip_case
    (v4) unterscheiden sich nur in einem Buchstaben und standen beide im
    selben Ordner. v3 liegt jetzt unter alt_v3/.
2026-07-16 fix(case): Fusion-Skriptordner-Struktur (aurapip_case/ + .manifest)
    Fusion findet nackte .py im +-Dialog nicht zuverlaessig - erwartet
    Ordner mit gleichnamiger .py + .manifest (wie selbst angelegte Skripte).
2026-07-16 feat(case): Lautsprecher ganz offen (GRILL_BARS=0 Default)
    Ivo: Membran soll voll sichtbar sein. Der 1.5-mm-Haltering bleibt
    (haelt den K28-Flansch, deckt nur den Metallrand ab).
2026-07-16 fix(case): Rest-Haut vor der Lautsprecher-Kammer beseitigt + 3 Stege
    Kammer-Schnitt endete 0.01 vor der Frontplatte -> hauchduenne Haut
    blieb als Deckflaeche in der Oeffnung stehen (Ivos Screenshot).
    Schnitte ueberlappen jetzt (Kammer +0.05 in die Platte, Oeffnung
    startet 0.2 dahinter). GRILL_BARS=3 (Ivo: lieber einer mehr).
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2026-07-16 fix(case): Kammer-Topf als Zentrierbund praezisiert (0.15/Seite statt 0.4)
    Antwort auf Ivos Frage zur Verbindung an der Rundung: Topf taucht 1mm
    in den Basis-Sitz = Zentrierung; Klemmung ueber Eckschrauben,
    Kammerdichtheit ueber eingeklebten Kammerdeckel.
